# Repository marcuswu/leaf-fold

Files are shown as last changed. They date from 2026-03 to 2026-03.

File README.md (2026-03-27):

# Leaf Fold
Leaf Fold is a 6x3+4keys column-staggered split portable folding keyboard using Ultra Low Profile (ULP) switches.

![Leaf Fold Pic]()

## Warning ##
This board is under active development and is not ready for builds yet. In particular, some of the models, the bill of materials, etc are not up to date.

## Introduction and Background

After building my first keyboard, a [Lily58](https://github.com/kata0510/Lily58), I started following [r/ErgoMechKeyboards](https://www.reddit.com/r/ErgoMechKeyboards/), [r/olkb](https://www.reddit.com/r/olkb/), and [r/MechanicalKeyboards](https://www.reddit.com/r/MechanicalKeyboards/). It was then that I came across the [mikefive](https://www.reddit.com/r/ErgoMechKeyboards/comments/1cfg3vr/mikefive_a_kailh_pg1316_keyboard/), a 5mm tall keyboard utilizing Kailh PG1316S keyswitches.

I had always been more interested in low profile keyboards than clacky mechanical keyboards with a lot of key travel, so the mikefive inspired me. I was not ready (and may never be) to reduce down to 5 columns like the mikefive, but I had been intending to learn to design a PCB for some time now.

I felt that the design of the mikefive could easily be altered to be even more portable by either being fully split or by a folding design. After [many iterations](https://www.reddit.com/r/ErgoMechKeyboards/comments/1g9hv4a/introducing_leaf_fold_an_ultra_portable_keyboard/), I designed and ultimately built the Leaf Fold. This repository is designed to provide the designs for it to allow others to build their own.

The initial version I shared on reddit had a couple of issues I wasn't happy with sharing:

* The board design prevented bluetooth connections from working
* The PG1316S switches did not provide a good experience
* The nice!view screen did not really add anything and was too easy to break when building this keyboard

Since then I have been working on my own switches and this board utilizes those.

## Using this repository

This repository contains:

* Models for the keyboard's case in STEP format with engineering drawings
* KiCAD project for the PCB

A [bill of materials](https://docs.google.com/spreadsheets/d/1gnvod9HGQc0NwxPJ2fzenmY7mPNX9EfSASZGwRChprs/edit?gid=0#gid=0) for constructing the keyboard is also available

## Build Guide

A build guide is in the works.

## TODO

* Ensure new ULP switches work
* Build it & test it
* Create a build guide
* Update the BoM (build it into this repo so it is versioned)

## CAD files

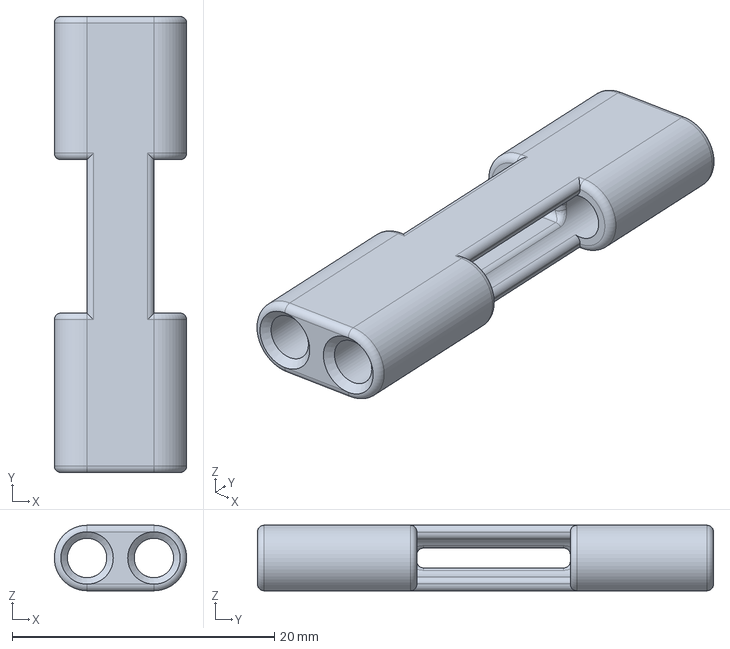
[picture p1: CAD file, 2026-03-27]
Case/leaf_fold3_middle_hinge.step
10.1 x 34.8 x 5.00 mm

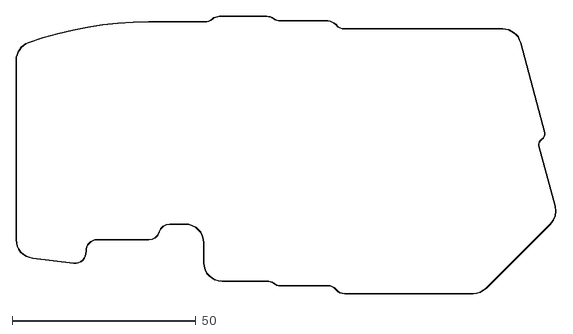
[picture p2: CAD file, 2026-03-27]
PCB/left/3leaf_left_v3.dxf
147.0 x 75.4

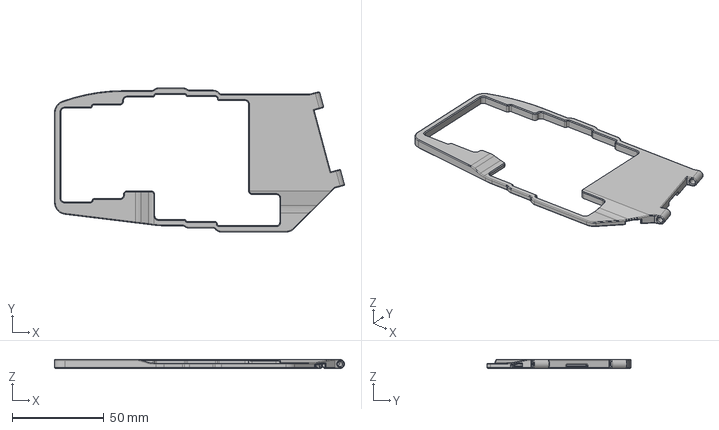
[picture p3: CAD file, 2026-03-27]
Case/leaf_fold3_left_case.step
157.7 x 78.4 x 5.00 mm

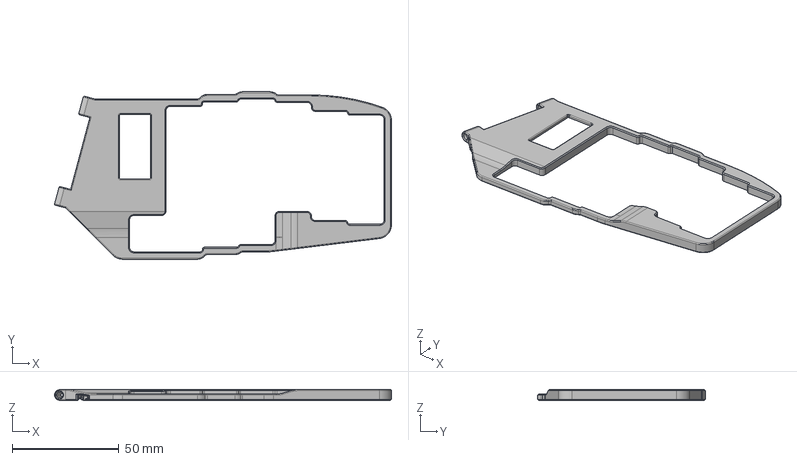
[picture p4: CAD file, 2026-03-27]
Case/leaf_fold3_right_case.step
157.7 x 78.4 x 5.00 mm

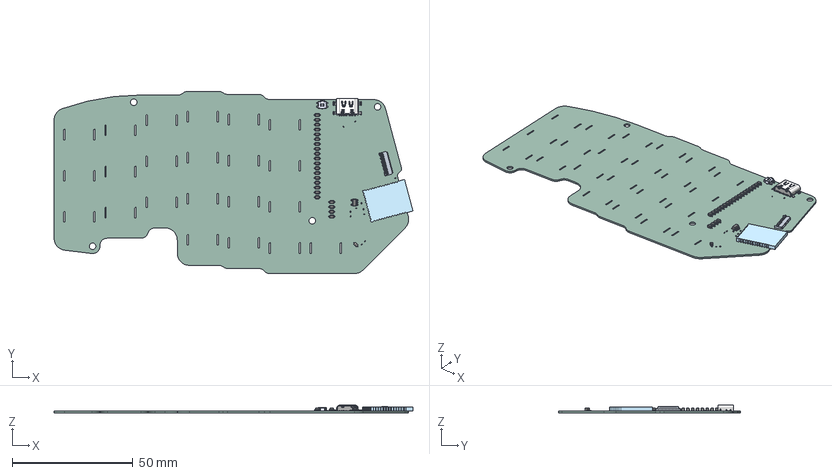
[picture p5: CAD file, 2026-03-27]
PCB/left/3leaf_left.step
148.5 x 75.4 x 3.16 mm
D_SOD-323 x 23
C_0201_0603Metric x 5
holyiot-18010-nrf52840
R_0201_0603Metric x 6
SOT-23-5
EVQ-P7A01P
3leaf_left_PCB

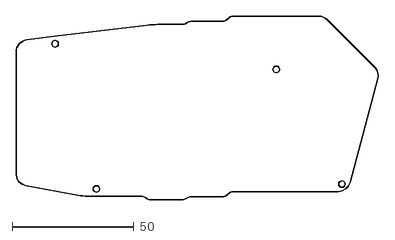
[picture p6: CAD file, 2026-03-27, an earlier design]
PCB/left/3leaf_left_v2.dxf
149.0 x 75.4

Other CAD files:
Case/leaf_fold3_left_case.dwg
Case/leaf_fold3_middle_hinge.dwg
Case/leaf_fold3_right_case.dwg
PCB/left/3leaf_left.dxf

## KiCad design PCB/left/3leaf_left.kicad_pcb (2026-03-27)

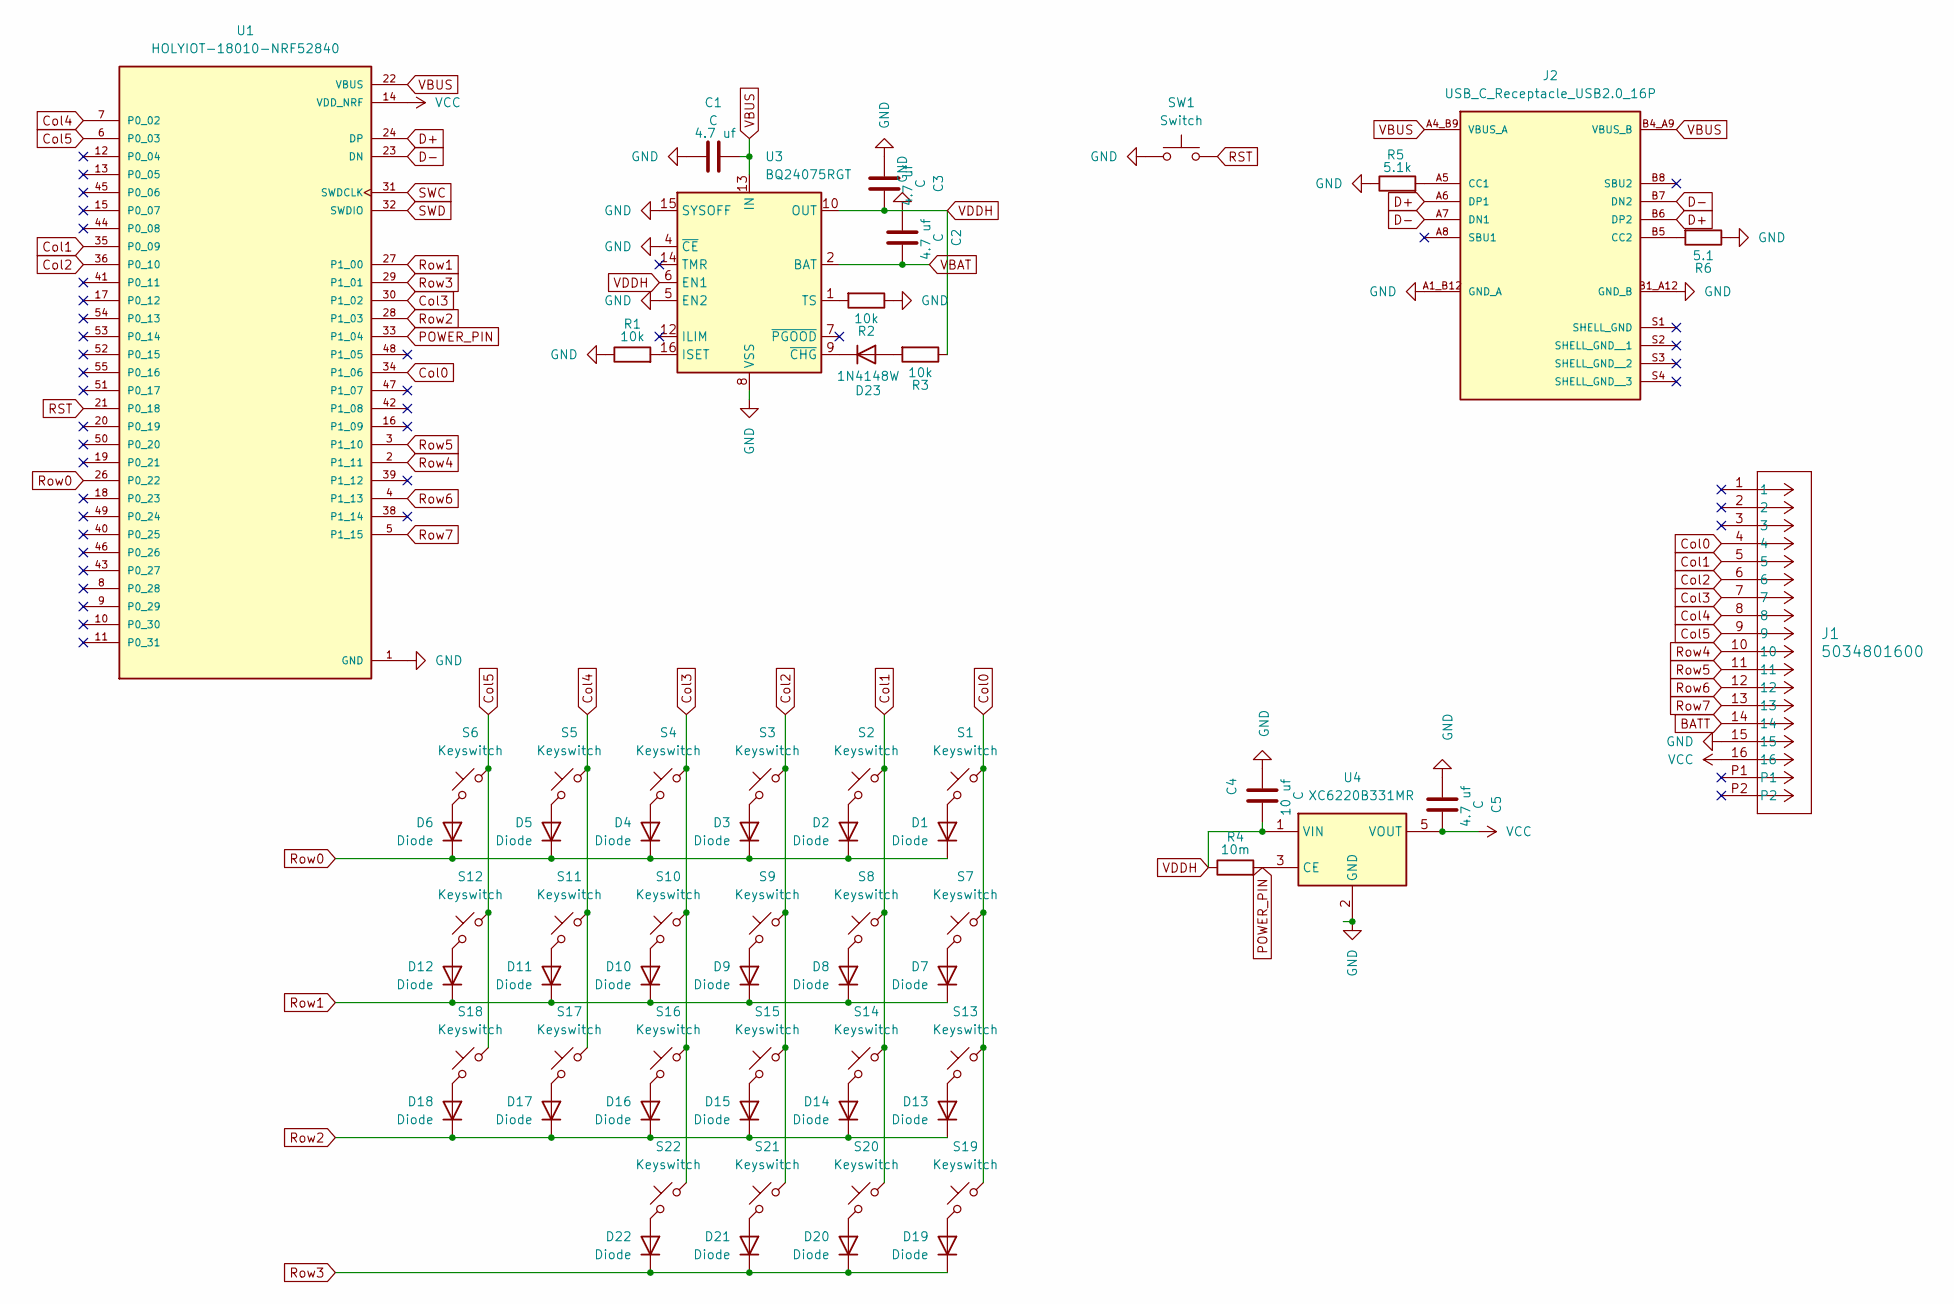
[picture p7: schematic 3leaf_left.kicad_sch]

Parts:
C1, C2, C3, C4, C5: C; C_0201_0603Metric
D1, D2, D3, D4, D5, D6, D7, D8, D9, D10, D11, D12, D13, D14, D15, D16, D17, D18, D19, D20, D21, D22: Diode; D_SOD-323
D23: 1N4148W; D_SOD-323
J1: 5034801600; CON_5034801600_MOL
J2: USB_C_Receptacle_USB2.0_16P; GCT_USB4500-03-1-A_REVA; PARTREV A
R1, R2, R3: 10k; R_0201_0603Metric
R4: 10m; R_0201_0603Metric
R5: 5.1k; R_0201_0603Metric
R6: 5.1; R_0201_0603Metric
S1, S2, S3, S4, S5, S6, S7, S8, S9, S10, S11, S12, S13, S14, S15, S16, S17, S18, S19, S20, S21, S22: Keyswitch; My_ULP_Scissor
SW1: Switch; EVQ_P7_PUC
U1: HOLYIOT-18010-NRF52840; XCVR_HOLYIOT-18010-NRF52840
U3: BQ24075RGT; VQFN-16-1EP_3x3mm_P0.5mm_EP1.6x1.6mm
U4: XC6220B331MR; SOT-23-5

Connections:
BATT: J1.14
Col0: J1.4, S1.1, S7.1, S13.1, S19.1, U1.34 (P1_06)
Col1: J1.5, S2.1, S8.1, S14.1, S20.1, U1.35 (P0_09)
Col2: J1.6, S3.1, S9.1, S15.1, S21.1, U1.36 (P0_10)
Col3: J1.7, S4.1, S10.1, S16.1, S22.1, U1.30 (P1_02)
Col4: J1.8, S5.1, S11.1, S17.1, U1.7 (P0_02)
Col5: J1.9, S6.1, S12.1, S18.1, U1.6 (P0_03)
D+: J2.A6 (DP1), J2.B6 (DP2), U1.24 (DP)
D-: J2.A7 (DN1), J2.B7 (DN2), U1.23 (DN)
unnamed: D1.2 (A), S1.2
unnamed: D2.2 (A), S2.2
unnamed: D3.2 (A), S3.2
unnamed: D4.2 (A), S4.2
unnamed: D5.2 (A), S5.2
unnamed: D6.2 (A), S6.2
unnamed: D7.2 (A), S7.2
unnamed: D8.2 (A), S8.2
unnamed: D9.2 (A), S9.2
unnamed: D10.2 (A), S10.2
unnamed: D11.2 (A), S11.2
unnamed: D12.2 (A), S12.2
unnamed: D13.2 (A), S13.2
unnamed: D14.2 (A), S14.2
unnamed: D15.2 (A), S15.2
unnamed: D16.2 (A), S16.2
unnamed: D17.2 (A), S17.2
unnamed: D18.2 (A), S18.2
unnamed: D19.2 (A), S19.2
unnamed: D20.2 (A), S20.2
unnamed: D21.2 (A), S21.2
unnamed: D22.2 (A), S22.2
unnamed: D23.2 (A), R3.2
unnamed: D23.1 (K), U3.9 (~CHG)
unnamed: J2.A5 (CC1), R5.2
unnamed: J2.B5 (CC2), R6.2
unnamed: R1.2, U3.16 (ISET)
unnamed: R2.2, U3.1 (TS)
POWER_PIN: R4.2, U1.33 (P1_04), U4.3 (CE)
RST: SW1.2, U1.21 (P0_18)
Row0: D1.1 (K), D2.1 (K), D3.1 (K), D4.1 (K), D5.1 (K), D6.1 (K), U1.26 (P0_22)
Row1: D7.1 (K), D8.1 (K), D9.1 (K), D10.1 (K), D11.1 (K), D12.1 (K), U1.27 (P1_00)
Row2: D13.1 (K), D14.1 (K), D15.1 (K), D16.1 (K), D17.1 (K), D18.1 (K), U1.28 (P1_03)
Row3: D19.1 (K), D20.1 (K), D21.1 (K), D22.1 (K), U1.29 (P1_01)
Row4: J1.10, U1.2 (P1_11)
Row5: J1.11, U1.3 (P1_10)
Row6: J1.12, U1.4 (P1_13)
Row7: J1.13, U1.5 (P1_15)
SWC: U1.31 (SWDCLK)
SWD: U1.32 (SWDIO)
VBAT: C2.1, U3.2 (BAT), U3.3 (BAT)
VBUS: C1.1, J2.A4_B9 (VBUS_A), J2.B4_A9 (VBUS_B), U1.22 (VBUS), U3.13 (IN)
VCC: C5.1, J1.16, U1.14 (VDD_NRF), U4.5 (VOUT)

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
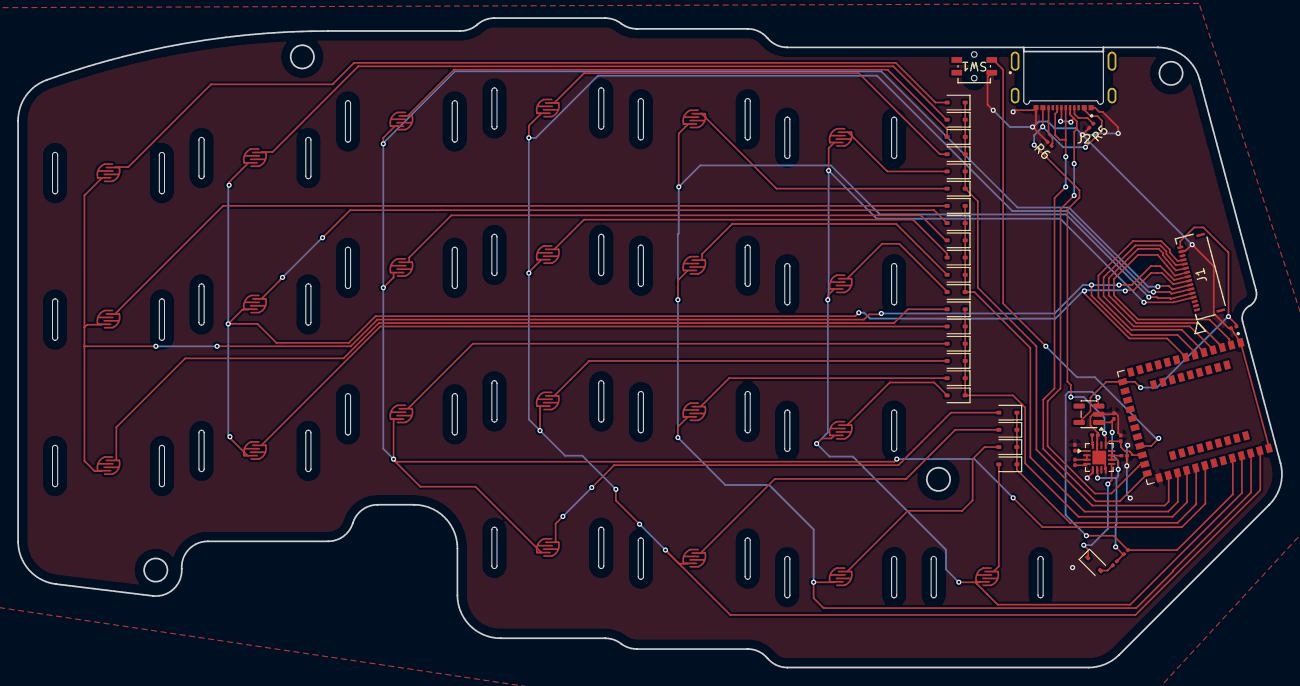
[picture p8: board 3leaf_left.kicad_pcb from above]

Board: 2 copper layers, 146.7 x 75.4 mm, 62 parts (0 on the bottom side), 51 nets.
